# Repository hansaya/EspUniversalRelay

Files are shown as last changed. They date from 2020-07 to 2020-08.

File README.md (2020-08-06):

# EspUniversalRelay
Universal Relay board with esp32

Features
* 3 isolated Relay outputs
* 3 non isolated inputs
* 1 isolated input
* Wide input voltage range
* Super capacitor to harvest energy from a garage door switch.
* Carbon and temperature sensor

#TODO
* Add a 5v and 3v out pins
* Add GND pins for the inputs

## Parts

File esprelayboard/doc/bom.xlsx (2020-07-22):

Part name | Part number | price | location
super cap | DSK-3R3H224U-HL | 1.81 | https://www.digikey.com/product-detail/en/elna-america/DSK-3R3H224U-HL/604-1020-1-ND/970232
6pin connector male | SM06B-GHS-TB | 0.58 | https://www.digikey.com/product-detail/en/SM06B-GHS-TB(LF)(SN)/455-1568-1-ND/807836/?itemSeq=331108771
6pin connector female | GHR-06V-S | 0.17 | https://www.digikey.com/product-detail/en/jst-sales-america-inc/GHR-06V-S/455-1596-ND/807818
pin header | SSHL-002T-P0.2 | 0.11 | https://www.digikey.com/product-detail/en/jst-sales-america-inc/SSHL-002T-P0-2/455-1606-1-ND/1642795
2pin connector male | SM02B-GHS-TB | 0.46 | https://www.digikey.com/product-detail/en/jst-sales-america-inc/SM02B-GHS-TB-LF-SN/455-1564-1-ND/807832
2pin connector female | GHR-02V-S | 0.12 | https://www.digikey.com/product-detail/en/GHR-02V-S/455-1592-ND/807814/?itemSeq=331108905
Total |  | 3.25

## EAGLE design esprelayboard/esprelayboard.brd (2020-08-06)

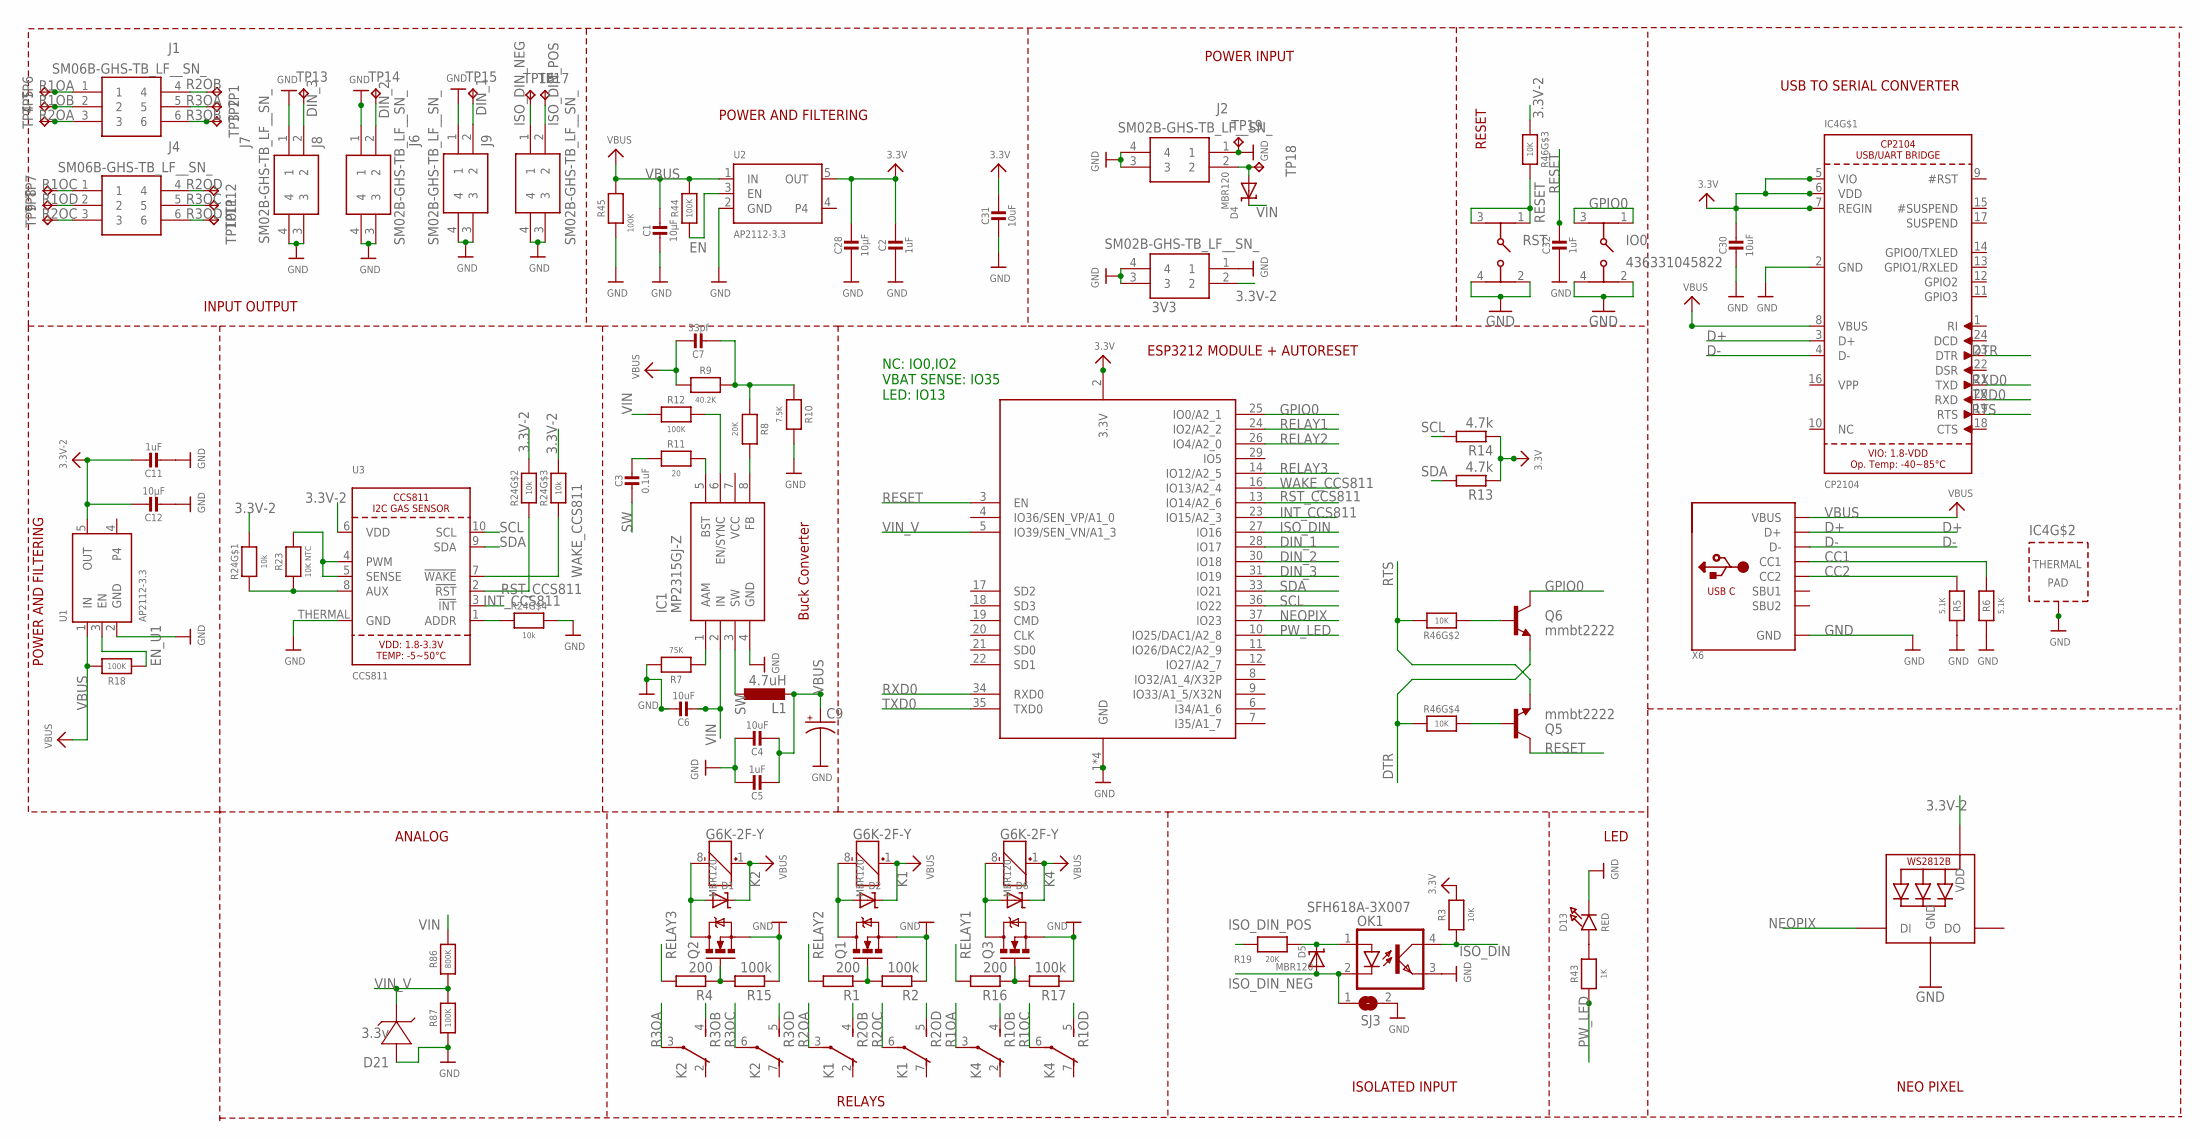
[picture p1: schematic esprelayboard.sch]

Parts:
3V3: SM02B-GHS-TB_LF__SN_; SM02BGHSTBLFSN
C1, C12, C28: 10µF; 0805-NO
C2, C5, C11, C32: 1uF; 0603-NO@1
C3: 0.1uF; 0603-NO@1
C4, C6: 10uF; 0603-NO@1
C7: 33pf; 0603-NO@1
C9: CPOL-USUD-6,3X5,8; UD-6,3X5,8_NICHICON
C30, C31: 10uF; 0805-NO
D1, D2, D4, D5, D6: MBR120; SOD-123
D13: RED; CHIPLED_0805_NOOUTLINE
D21: 3.3v; SOD123
IC1: MP2315GJ-Z; SOT65P280X100-8N
IC4: CP2104; QFN24_4MM_SMSC
IO0: 436331045822
J1, J4: SM06B-GHS-TB_LF__SN_; SM06B-GHS-TB
J2, J6, J7, J8, J9: SM02B-GHS-TB_LF__SN_; SM02BGHSTBLFSN
K1, K2, K4: G6K-2F-Y
L1: 4.7uH; L2825P
LED1: WS2812B3535; LED3535
OK1: SFH618A-3X007; SMD4-7
Q1, Q2, Q3: MOSFET-NCHANNELAO3404A; SOT23-3
Q5, Q6: mmbt2222; SOT23-3
R1, R4, R16: 200; R0603
R2, R15, R17: 100k; R0603
R3: 10K; 0603-NO
R5, R6: 5.1K; 0603-NO
R7: 75K; 0603-NO
R8, R19: 20K; 0603-NO
R9: 40.2K; 0603-NO
R10: 7.5K; 0603-NO
R11: 20; 0603-NO
R12, R18, R44, R45, R87: 100K; 0603-NO
R13, R14: 4.7k; R0603
R23: 10K NTC; _0402
R24: 10k; RESPACK_4X0603
R43: 1K; 0603-NO
R46: 10K; RESPACK_4X0603
R86: 800K; 0603-NO
RST: 436331045822
SJ3: SJ
TP1, TP2, TP3, TP4, TP5, TP6, TP7, TP8, TP9, TP10, TP11, TP12, TP13, TP14, TP15, TP16, TP17, TP18, TP19: TPTP14SQ; TP14SQ
U1, U2: AP2112-3.3; SOT23-5
U3: CCS811
X6: USB_C; USB_C_CUSB31-CFM2AX-01-X
X8: ESP32_WROOM32_SKINNY; WROOM32_SKINNY

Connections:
3.3V: C2.1, C28.1, C31.1, R3.1, R13.1, R14.1, U2.5 (OUT), X8.2 (3.3V)
3.3V-2: 3V3.2, C11.1, C12.1, C30.1, IC4.5 (VIO), IC4.6 (VDD), IC4.7 (REGIN), LED1.2 (VDD), R24.6 (2), R24.7 (2), R24.8 (2), R46.3 (1), U1.5 (OUT), U3.6 (VDD)
CC1: R6.2, X6.A5 (CC1)
CC2: R5.2, X6.B5 (CC2)
D+: IC4.3 (D+), X6.A6 (D+), X6.B6 (D+)
D-: IC4.4 (D-), X6.A7 (D-), X6.B7 (D-)
DIN_1: J6.2, TP15.TP, X8.28 (IO17)
DIN_2: J8.2, TP14.TP, X8.30 (IO18)
DIN_3: J7.2, TP13.TP, X8.31 (IO19)
DTR: IC4.23 (DTR), Q6.2 (E), R46.4 (1)
EN: R44.1, U2.3 (EN)
EN_U1: R18.1, U1.3 (EN)
GND: 3V3.1, 3V3.3, 3V3.4, C1.2, C2.2, C4.1, C5.1, C6.1, C9.-, C11.2, C12.2, C28.2, C30.2, C31.2, C32.2, D13.C, D21.A (+), IC1.4 (GND), IC4.2 (GND), IC4.THERM (TP), IO0.2 (4), IO0.4 (2), J2.1, J2.3, J2.4, J6.1, J6.3, J6.4, J7.1, J7.3, J7.4, J8.1, J8.3, J8.4, J9.3, J9.4, LED1.4 (GND), OK1.3 (EMIT), Q1.2 (S), Q2.2 (S), Q3.2 (S), R2.1, R5.1, R6.1, R7.2, R10.2, R15.1, R17.1, R24.5 (2), R45.1, R87.1, RST.2 (4), RST.4 (2), SJ3.2, TP19.TP, U1.2 (GND), U2.2 (GND), U3.THERMAL (GND), X6.A1B12 (GND), X6.B1A12 (GND), X8.1 (GND), X8.15 (GND), X8.38 (GND), X8.P$1 (GND)
GPIO0: IO0.1 (3), IO0.3 (1), Q6.3 (C), X8.25 (IO0/A2_1)
INT_CCS811: U3.3 (!INT), X8.23 (IO15/A2_3)
ISO_DIN: OK1.4 (COL), R3.2, X8.27 (IO16)
ISO_DIN_NEG: D5.A, J9.1, OK1.2 (C), SJ3.1, TP16.TP
ISO_DIN_POS: J9.2, R19.2, TP17.TP
unnamed: D13.A, R43.2
unnamed: Q1.1 (G), R1.1, R2.2
unnamed: D2.A, K1.8 (-), Q1.3 (D)
unnamed: D4.A, J2.2, TP18.TP
unnamed: Q2.1 (G), R4.1, R15.2
unnamed: Q3.1 (G), R16.1, R17.2
unnamed: D1.A, K2.8 (-), Q2.3 (D)
unnamed: D6.A, K4.8 (-), Q3.3 (D)
unnamed: D5.C, OK1.1 (A), R19.1
unnamed: R23.2, U3.4 (PWM), U3.5 (SENSE)
unnamed: R23.1, R24.1, U3.8 (AUX)
unnamed: R24.4 (1), U3.1 (ADDR)
unnamed: IC1.8 (FB), R8.2
unnamed: C7.2, R8.1, R9.2, R10.1
unnamed: IC1.5 (BST), R11.2
unnamed: IC1.1 (AAM), R7.1
unnamed: IC1.6 (EN/SYNC), R12.2
unnamed: C3.1, R11.1
unnamed: Q5.1 (B), R46.5 (2)
unnamed: Q6.1 (B), R46.2 (1)
NEOPIX: LED1.1 (DI), X8.37 (IO23)
PW_LED: R43.1, X8.10 (IO25/DAC1/A2_8)
R1OA: J1.1, K4.3, TP6.TP
R1OB: J1.2, K4.4 (S), TP5.TP
R1OC: J4.1, K4.6, TP7.TP
R1OD: J4.2, K4.5 (S), TP8.TP
R2OA: J1.3, K1.3, TP4.TP
R2OB: J1.4, K1.4 (S), TP1.TP
R2OC: J4.3, K1.6, TP9.TP
R2OD: J4.4, K1.5 (S), TP12.TP
R3OA: J1.5, K2.3, TP2.TP
R3OB: J1.6, K2.4 (S), TP3.TP
R3OC: J4.5, K2.6, TP11.TP
R3OD: J4.6, K2.5 (S), TP10.TP
RELAY1: R16.2, X8.24 (IO2/A2_2)
RELAY2: R1.2, X8.26 (IO4/A2_0)
RELAY3: R4.2, X8.14 (IO12/A2_5)
RESET: C32.1, Q5.3 (C), R46.6 (2), RST.1 (3), RST.3 (1), X8.3 (EN)
RST_CCS811: R24.2 (1), U3.2 (!RST), X8.13 (IO14/A2_6)
RTS: IC4.19 (RTS), Q5.2 (E), R46.7 (2)
RXD0: IC4.21 (TXD), X8.34 (RXD0)
SCL: R14.2, U3.10 (SCL), X8.36 (IO22)
SDA: R13.2, U3.9 (SDA), X8.33 (IO21)
SW: C3.2, IC1.3 (SW), L1.1
TXD0: IC4.20 (RXD), X8.35 (TXD0)
VBUS: C1.1, C4.2, C5.2, C7.1, C9.+, D1.C, D2.C, D6.C, IC4.8 (VBUS), K1.1 (+), K2.1 (+), K4.1 (+), L1.2, R9.1, R18.2, R44.2, R45.2, U1.1 (IN), U2.1 (IN), X6.A4B9 (VBUS), X6.B4A9 (VBUS)
VIN: C6.2, D4.C, IC1.2 (IN), R12.1, R86.2
VIN_V: D21.C (-), R86.1, R87.2, X8.5 (IO39/SEN_VN/A1_3)
WAKE_CCS811: R24.3 (1), U3.7 (!WAKE), X8.16 (IO13/A2_4)

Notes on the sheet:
RESET
LED
ESP3212 MODULE + AUTORESET
NC: IO0,IO2 VBAT SENSE: IO35 LED: IO13
USB TO SERIAL CONVERTER
POWER AND FILTERING
Buck Converter
INPUT OUTPUT
ANALOG
RELAYS
ISOLATED INPUT
NEO PIXEL
POWER INPUT

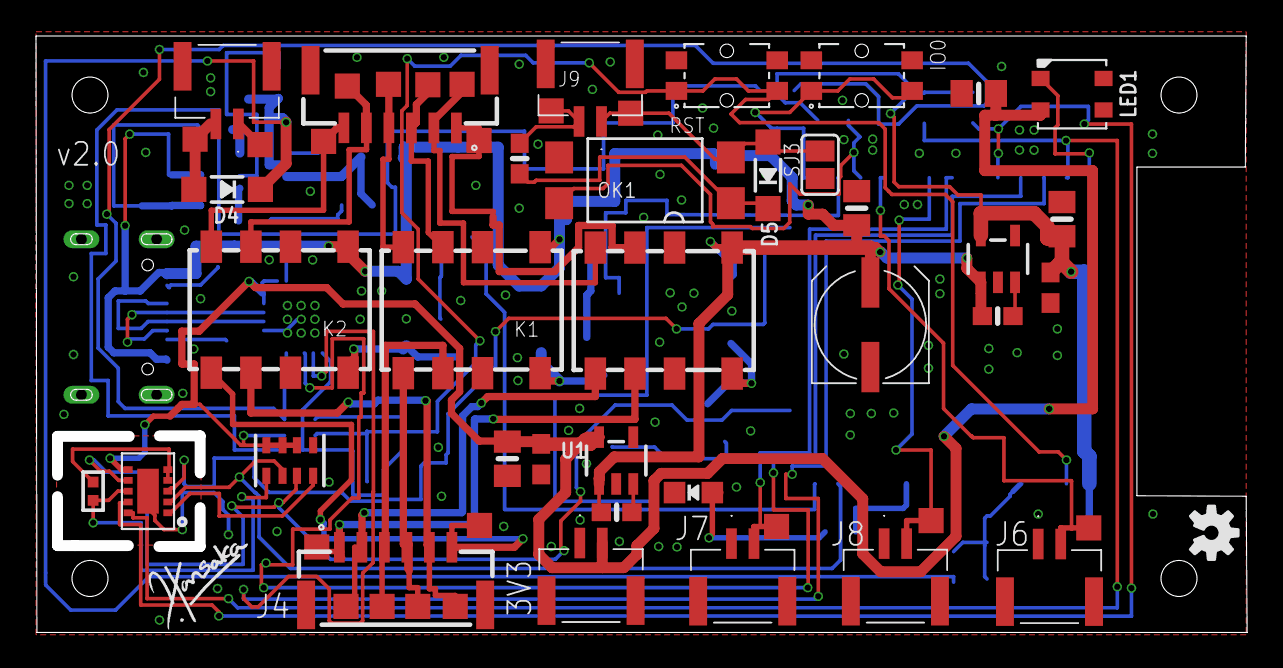
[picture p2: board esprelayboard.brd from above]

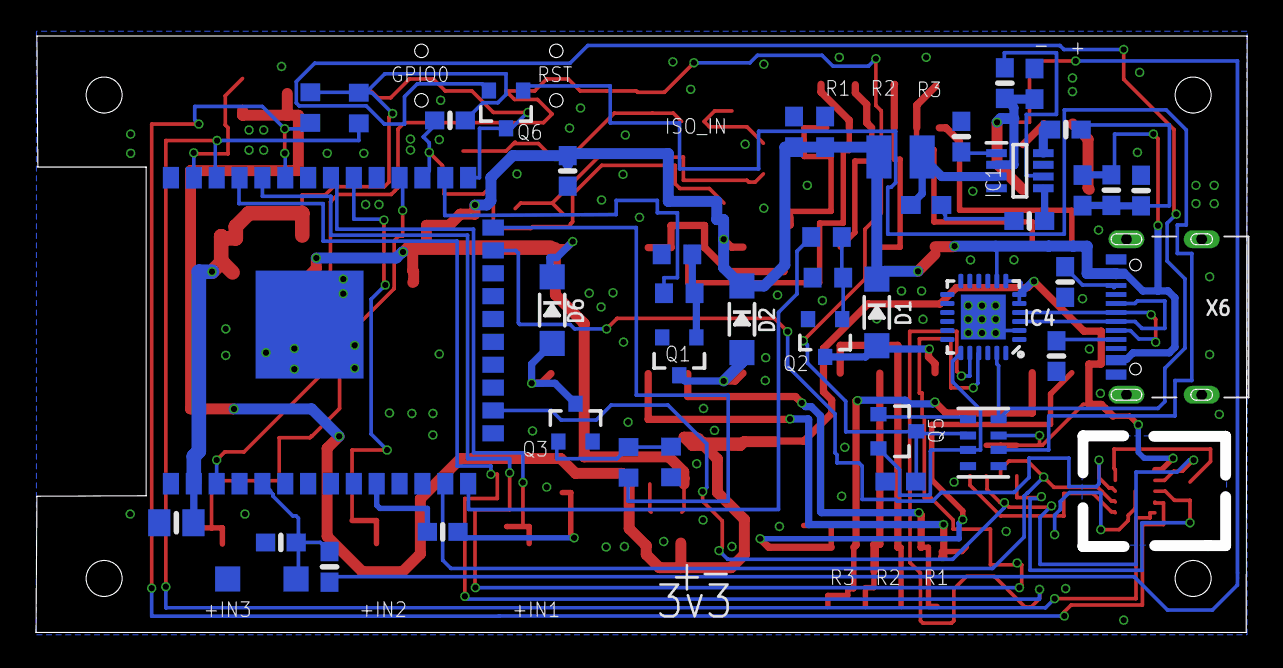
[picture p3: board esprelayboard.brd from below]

Board: 2 copper layers, 67.3 x 33.1 mm, 98 parts (43 on the bottom side), 67 nets.

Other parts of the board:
U$38: SIGNATURE
U$39: OSHW-LOGO-S

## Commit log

2020-06-22 v1 layout
    [esprelayboard.brd, esprelayboard.sch]
2020-07-01 final board files
    [esprelayboard.brd, esprelayboard.sch]
2020-07-22 doc updates
    [bom.xlsx]
2020-07-24 bug fix
    [esprelayboard.brd, esprelayboard.sch]

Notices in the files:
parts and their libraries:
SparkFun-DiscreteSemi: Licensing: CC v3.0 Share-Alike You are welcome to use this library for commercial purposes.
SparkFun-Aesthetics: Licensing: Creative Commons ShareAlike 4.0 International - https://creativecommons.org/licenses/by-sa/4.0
